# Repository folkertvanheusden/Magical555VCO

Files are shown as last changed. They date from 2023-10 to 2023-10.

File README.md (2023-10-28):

Magical555VCO
-------------

This is a very simple 555 timer based dual VCO.
It fits nicely in any eurorack.

Sample output: https://vanheusden.com/permshare/magical555vco-v0.2.flac
or listen in your browser at: https://vanheusden.com/electronics/Magical555VCO/audio-player.php

* schematics are under media/magical555vco.pdf

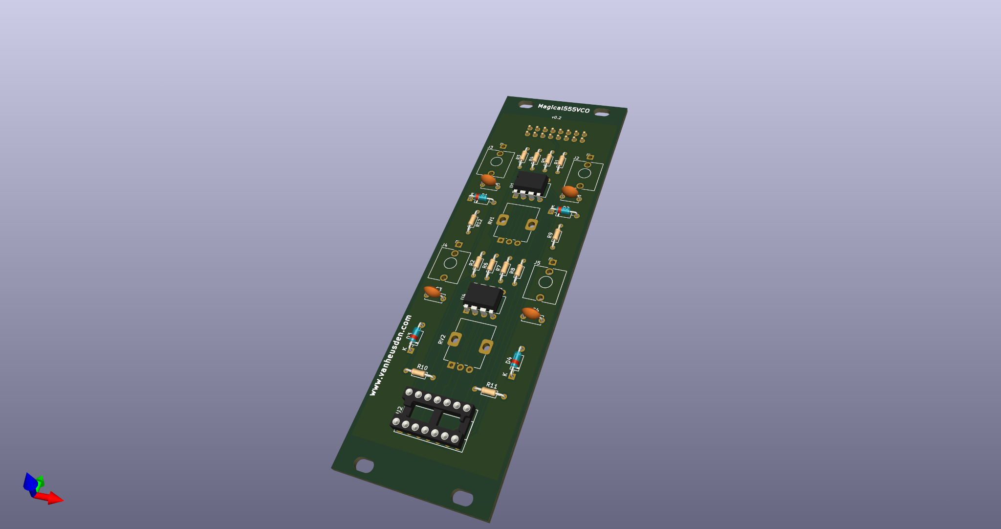
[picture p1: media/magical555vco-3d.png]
3D


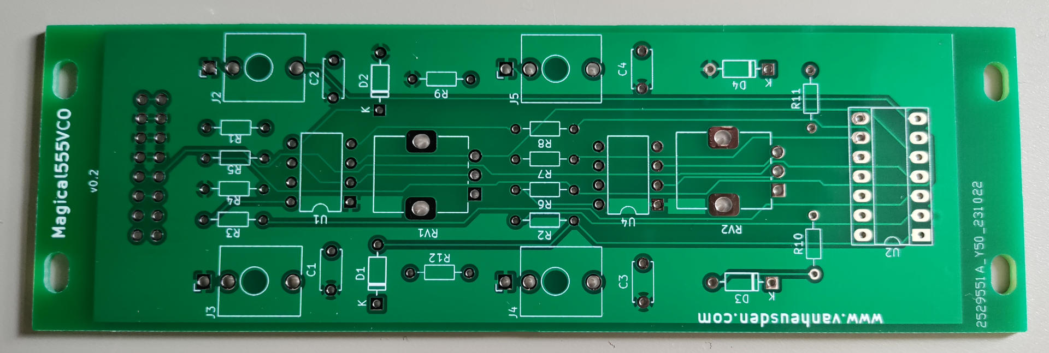
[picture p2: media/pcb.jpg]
PCB


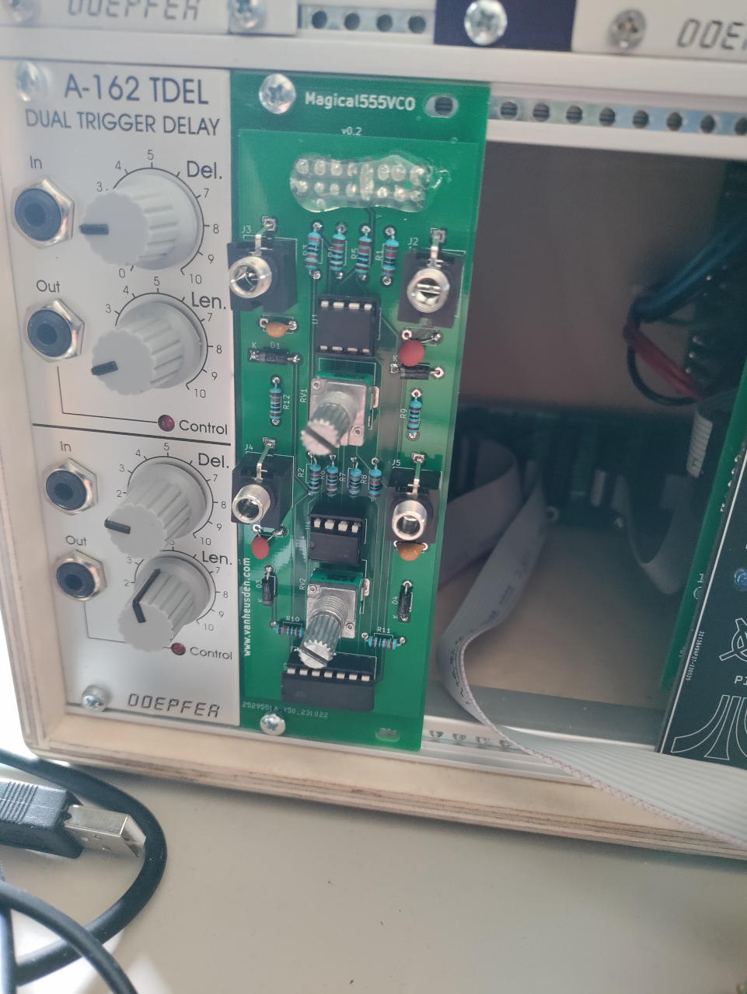
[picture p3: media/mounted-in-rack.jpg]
installed


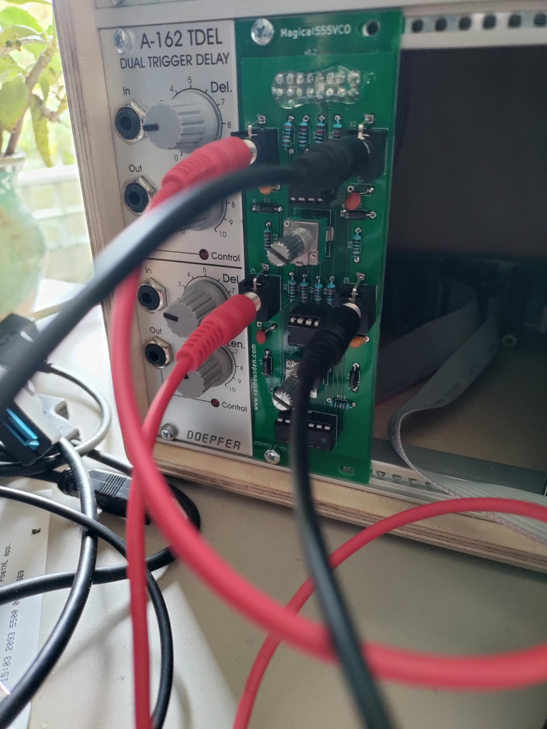
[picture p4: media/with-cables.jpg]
in use


Folkert van Heusden <mail@vanheusden.com>

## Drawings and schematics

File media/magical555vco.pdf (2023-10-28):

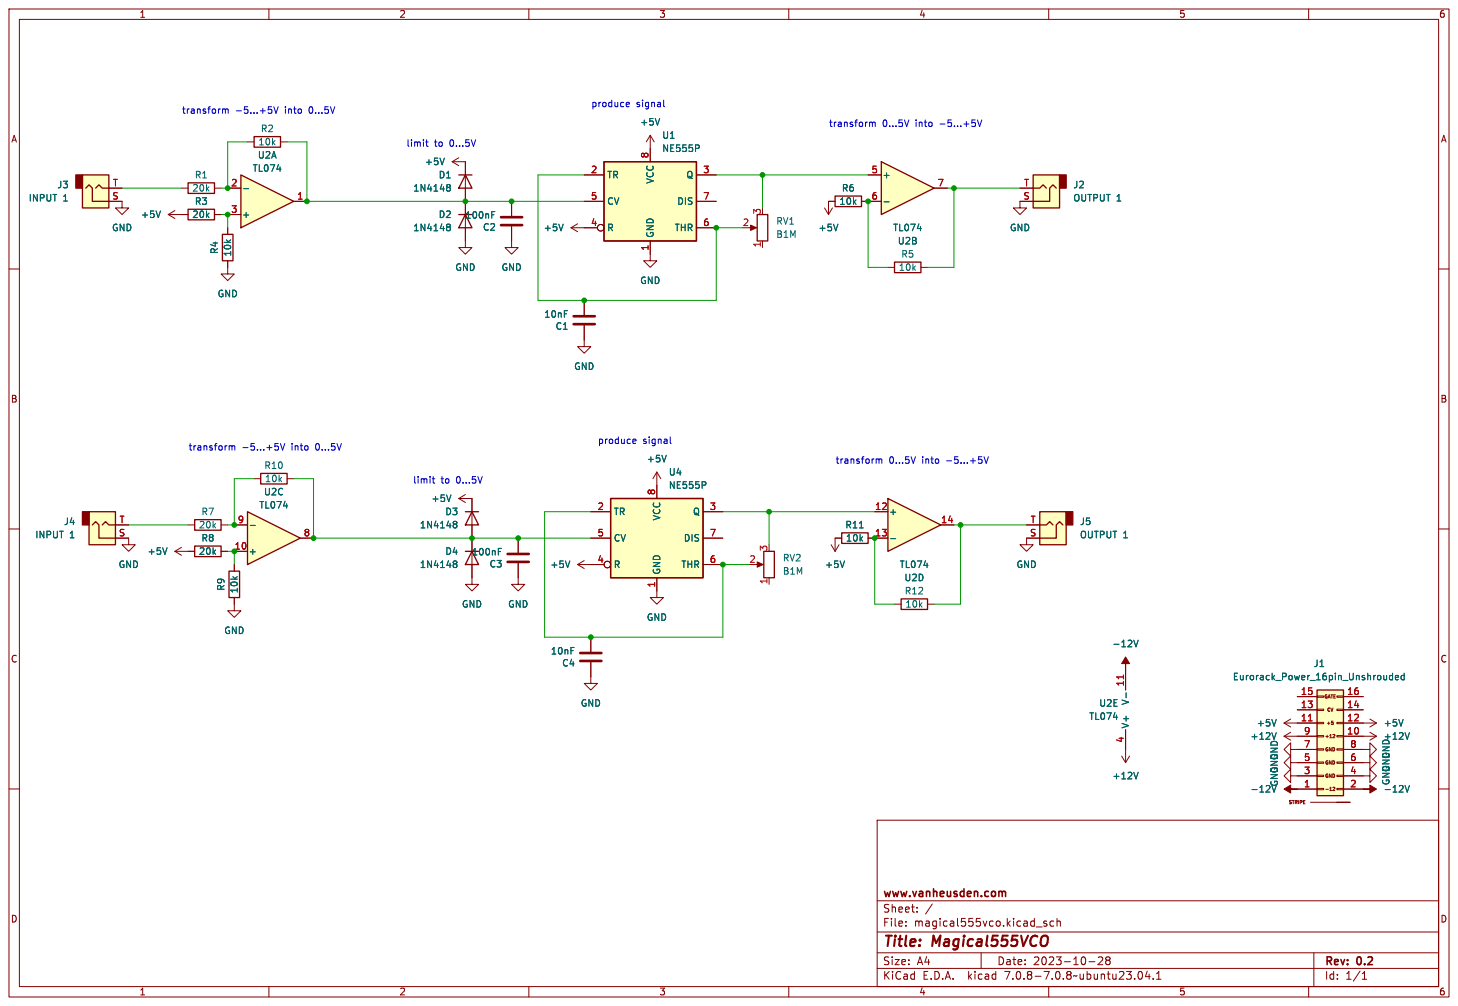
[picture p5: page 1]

File: magical555vco.kicad_sch Sheet: / www.vanheusden.com

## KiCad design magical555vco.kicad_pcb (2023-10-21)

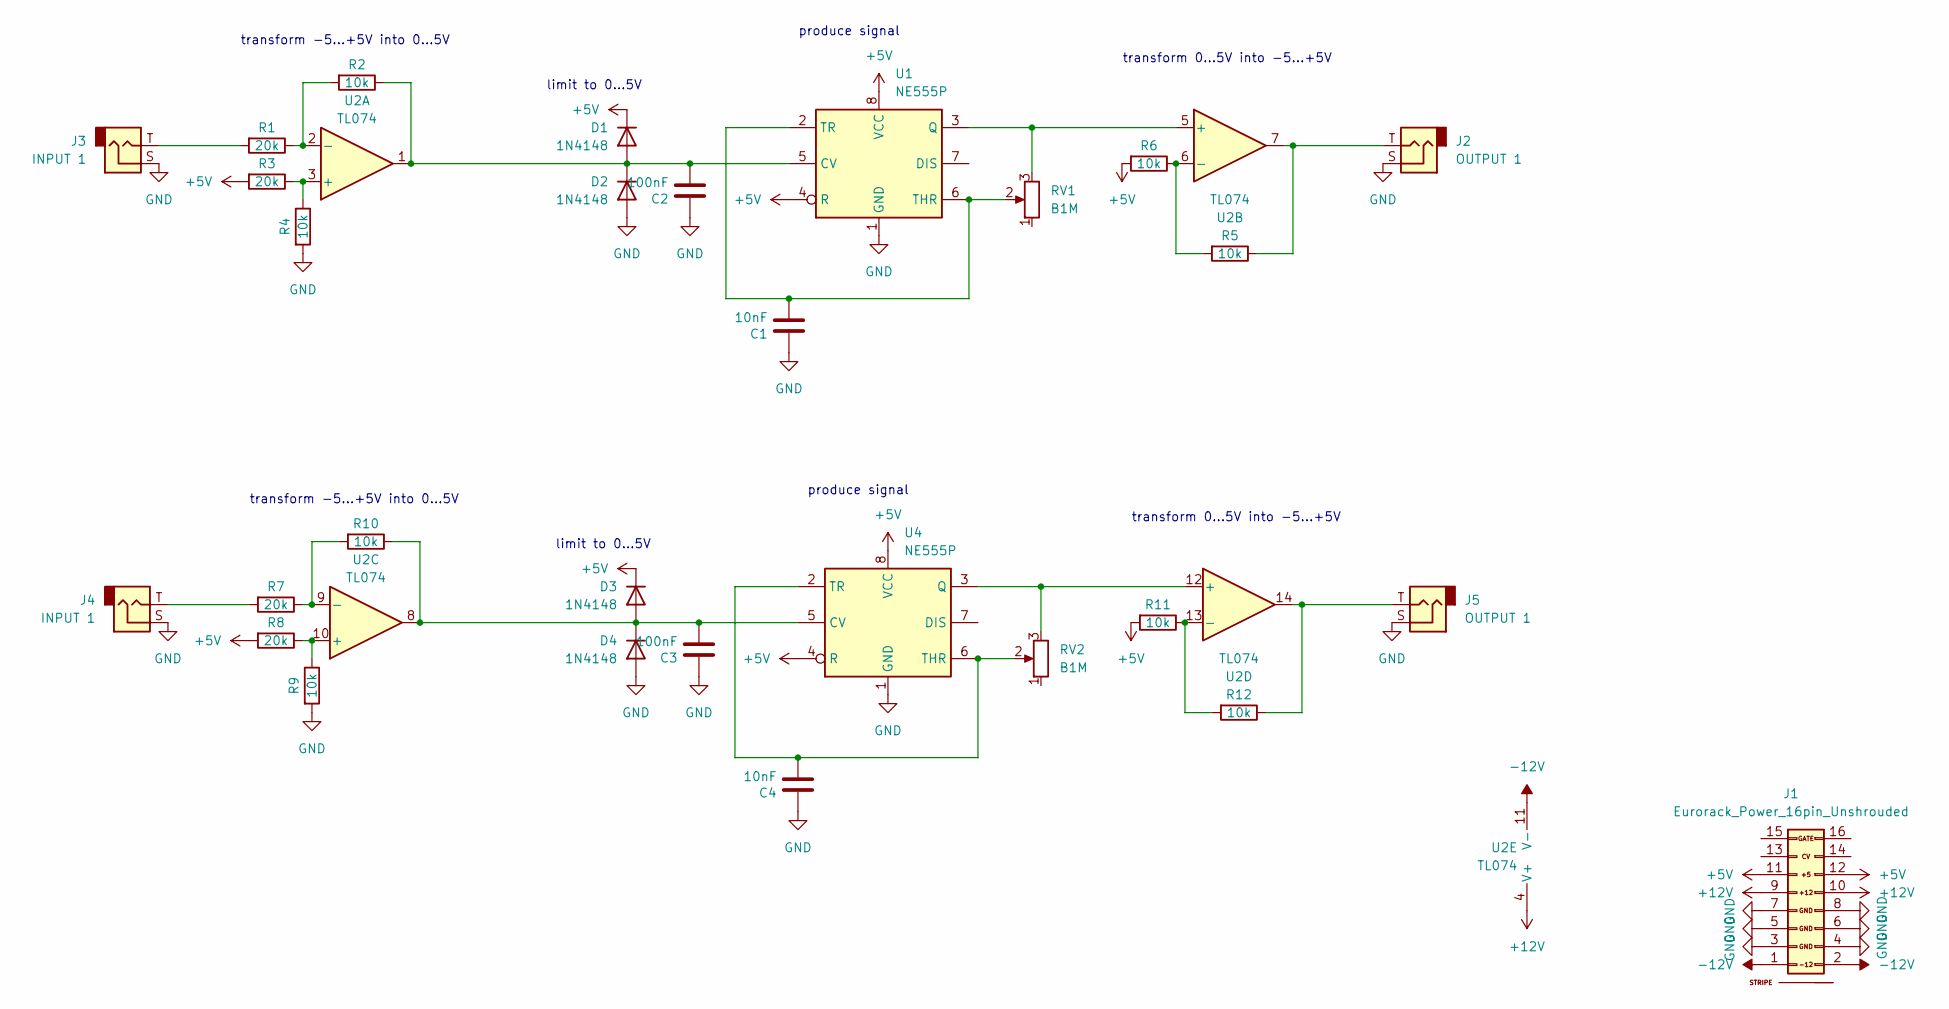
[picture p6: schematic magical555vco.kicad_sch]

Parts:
C1, C4: 10nF; C_Disc_D5.0mm_W2.5mm_P5.00mm
C2, C3: 100nF; C_Disc_D5.0mm_W2.5mm_P5.00mm
D1, D2, D3, D4: 1N4148; D_DO-35_SOD27_P7.62mm_Horizontal
J1: Eurorack_Power_16pin_Unshrouded; Pins_2x08_2.54mm_TH_EurorackPower; Part Number 1-1602FBV0T
J2, J5: OUTPUT 1; Jack_3.5mm_QingPu_WQP-PJ398SM_Vertical_CircularHoles
J3, J4: INPUT 1; Jack_3.5mm_QingPu_WQP-PJ398SM_Vertical_CircularHoles
R1, R3, R7, R8: 20k; R_Axial_DIN0204_L3.6mm_D1.6mm_P7.62mm_Horizontal
R2, R4, R5, R6, R9, R10, R11, R12: 10k; R_Axial_DIN0204_L3.6mm_D1.6mm_P7.62mm_Horizontal
RV1, RV2: B1M; Potentiometer_Alps_RK09K_Single_Vertical
U1, U4: NE555P; DIP-8_W7.62mm
U2: TL074; DIP-14_W7.62mm_Socket_LongPads

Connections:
+5V: D1.1 (K), D3.1 (K), J1.11 (5V), J1.12 (5V), R3.2, R6.2, R8.2, R11.2, U1.4 (R), U1.8 (VCC), U4.4 (R), U4.8 (VCC)
+12V: J1.9 (+12V), J1.10 (+12V), U2.4 (V+)
-12V: J1.1 (-12V), J1.2 (-12V), U2.11 (V-)
GND: C1.1, C2.1, C3.1, C4.1, D2.2 (A), D4.2 (A), J1.3 (GND), J1.4 (GND), J1.5 (GND), J1.6 (GND), J1.7 (GND), J1.8 (GND), J2.S, J3.S, J4.S, J5.S, R4.2, R9.2, U1.1 (GND), U4.1 (GND)
unnamed: C2.2, D1.2 (A), D2.1 (K), R2.1, U1.5 (CV), U2.1
unnamed: C3.2, D3.2 (A), D4.1 (K), R10.1, U2.8, U4.5 (CV)
unnamed: J2.T, R5.1, U2.7
unnamed: J3.T, R1.2
unnamed: J4.T, R7.2
unnamed: J5.T, R12.1, U2.14
unnamed: RV1.3, U1.3 (Q), U2.5 (+)
unnamed: C1.2, RV1.2, U1.2 (TR), U1.6 (THR)
unnamed: R3.1, R4.1, U2.3 (+)
unnamed: R1.1, R2.2, U2.2 (-)
unnamed: R5.2, R6.1, U2.6 (-)
unnamed: R8.1, R9.1, U2.10 (+)
unnamed: R7.1, R10.2, U2.9 (-)
unnamed: RV2.3, U2.12 (+), U4.3 (Q)
unnamed: R11.1, R12.2, U2.13 (-)
unnamed: C4.2, RV2.2, U4.2 (TR), U4.6 (THR)

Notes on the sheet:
limit to 0...5V
transform 0...5V into -5...+5V
produce signal
transform -5...+5V into 0...5V

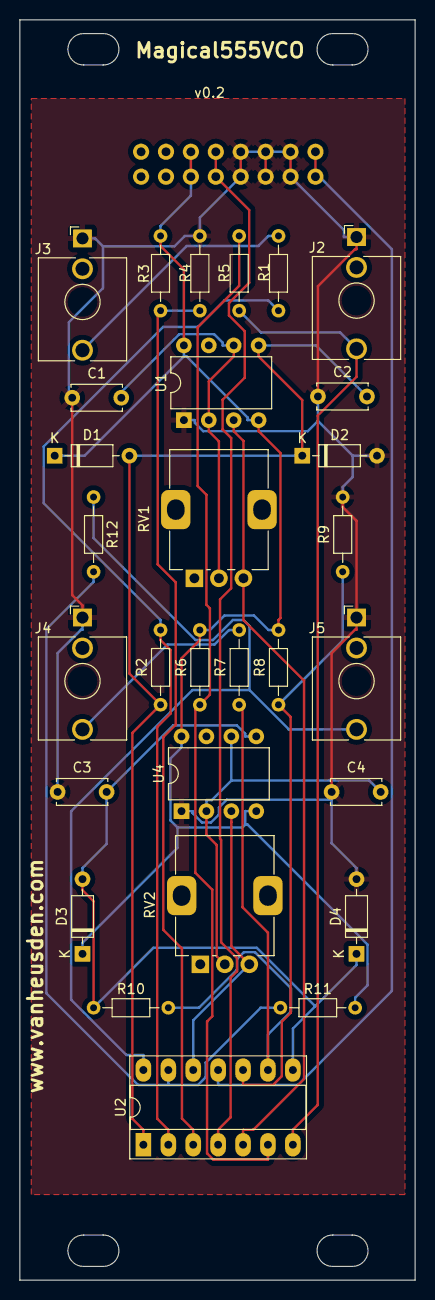
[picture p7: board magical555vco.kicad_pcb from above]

Board: 2 copper layers, 40.3 x 128.5 mm, 30 parts (1 on the bottom side), 20 nets.

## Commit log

2023-10-14 basic version, 1 channel
    [magical555vco.kicad_pcb, magical555vco.kicad_sch]
2023-10-14 2 modules, potmeter
    [magical555vco.kicad_pcb, magical555vco.kicad_sch]
